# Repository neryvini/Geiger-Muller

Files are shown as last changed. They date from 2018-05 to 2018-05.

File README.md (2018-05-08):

# Geiger-Muller
Projeto desenvolvido durante a disciplina de TG para o curso de engenharia de energia da UFABC.

Resumo
--------

Detectores de radiação baseados em câmaras de gás continuam sendo utilizados para a
verificação de radioatividade, são diversos os modelos e princípios de funcionamento, cada
um com uma especificidade característica do fenômeno e caracterização a se observar. Neste
trabalho, desenvolveu um detector de radiação a gás, conhecido pelo nome de contador
Geiger-Müller.

Este desenvolvimento incluiu o aperfeiçoamento de uma fonte de alta voltagem ajustável,
compatível com os mais diversos modelos comerciais de tubos Geiger-Müller. Foi do escopo
deste projeto a implementação de um sistema microprocessado para a contagem dos
pulsos, conversão em taxa de dose de radiação, transmissão via interface e protocolo de
comunicação industrial, além de informar em tempo real para o usuário por meio de uma
tela de LCD os parâmetros de radiação detectados.

Testou-se o produto desenvolvido com os tubos SI-3BG e SBM-20, em ambos os testes os
valores detectados para a radiação de fundo foram consistentes com o esperado.

Palavras-chave: Eletrônica nuclear; Contador Geiger-Müller; Sistemas microprocessados.

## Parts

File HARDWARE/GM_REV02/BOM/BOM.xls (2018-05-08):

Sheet: BOM
Des.Ref. | Valor | Tipo
C1 | 10uF x 16V | POLCAP
C2 | 10uF x 16V | POLCAP
C3 | 100nF x 50V | CAP
C4 | 1nF x 50V | CAP
C5 | 10nF | CAP
C6 | 10n 1000V | CAP200
C7 | 10n 1000V | CAP200
C8 | 10n 1000V | CAP200
C9 | 220pF | CAP
C10 | 100uF x 50V | POLCAP
C11 | 100uF x 50V | POLCAP
C12 | 100nF x 50V | CAP_0805
C13 | 100nF x 50V | CAP_0805
C14 | 100nF x 50V | CAP
C15 | 100nF x 50V | CAP
C16 | 100nF x 50V | CAP
C17 | 100nF x 50V | CAP
C18 | 680uF x 50V | POLCAP
C19 | 220uF x 25V | POLCAP
C20 | 100n | CAP_0805
C21 | 100nF | CAP_0805
C22 | 100nF | CAP_0805
C23 | 22pF | CAP_0805
C24 | 22pF | CAP_0805
C25 | 100nF | CAP_0805
C26 | 100nF | CAP_0805
C27 | 100nF | CAP_0805
D1 | 1N4937 | DIODE
D2 | 1N4937 | DIODE
D3 | 1N4937 | DIODE
D4 | 3mm Round | LED-3R_Red
D5 | 1N5824 | DIO_SCHOTTKY
D6 | LED | DIODE_0805
D7 | LED | DIODE_0805
D8 | 1N4148 | DIODE_0805
DS1 | DISPLAY 1602 | TUXGR_16X2_R2
J1 | Jumper 5mm | OSTTA020161B
J2 | soldered | JUMPER 2
J3 | CON +24V | HDR-1x2
J4 | header | 5103308-1
J5 | CON HV | HDR-1x2
J6 | CON RS485 | HDR-1x3
L1 | 100uH - radial | IND
L2 | 10mH | 7447471
L3 | 33uH | B82477G2
L4 | 1uH | IND_0805
LS1 | Buzzer 5VDC | AST-01508MR-R
Q1 | MPSA42 | MPSA42
Q2 | 2N3904 | 2N3904
Q3 | 2N3904 | 2N3904
Q4 | 2N3904 | 2N3904
Q5 | BC817 | BC817
R1 | 33k | RES
R2 | 33k | RES
R3 | 3K | RES
R4 | 100R | 3296W
R5 | 100k | RES
R6 | 10M | RES
R7 | 10k | RES
R8 | 100k | RES
R9 | 47k | RES
R10 | 100K | RES
R11 | 470k | RES
R12 | 10k | RES
R13 | 1k | RES
R14 | 1M | RES_0805
R15 | 100K | RES_0805
R16 | 2K2 | RES_0805
R17 | 10k | RES_0805
R18 | 10k | RES_0805
R19 | 10k | RES_0805
R20 | 120R | RES_0805
R21 | 470R | RES_0805
R22 | 470R | RES_0805
R23 | 2K2 | RES_0805
R24 | 10k | RES_0805
R25 | 10k | RES_0805
R26 | 10K | 3006P
R27 | 220R | RES_0805
R28 | 10k | RES_0805
R29 | 10M | RES
R30 | 10M | RES
R31 | 10M | RES
R32 | 10M | RES
R33 | 10M | RES
R34 | VAR 25V | 711241
R35 | 10M | RES
R36 | 10M | RES
R37 | 10M | RES
R38 | 10M | RES
R39 | 10M | RES
R40 | 100K | RES
R41 | 100R 1W | RES_2512
U1 | LM555 | LM555CJ
U2 | LM555 | LM555CJ
U3 | REG. TENSAO | LM2596S-5.0
U4 | MAX485CSA | MAX485CSA
U5 | atmega328p-au | ATMEGA88_TQFP
Y1 | 16MHz | HC49S

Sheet: Plan1
Referência | Descrição | Encapsulamento | Valor
C1 | Capacitor eletrolítico - 5x12 mm | POLCAP PTH | 10uF x 16V
C2 | Capacitor eletrolítico - 5x12 mm | POLCAP PTH | 10uF x 16V
C3 | Capacitor disco cerâmico | CAP PTH | 100nF x 50V
C4 | Capacitor disco cerâmico | CAP PTH | 1nF x 50V
C5 | Capacitor disco cerâmico | CAP PTH | 10nF
C6 | Capacitor cerâmico | CAP200 PTH | 10nF x 1000V
C7 | Capacitor cerâmico | CAP200 PTH | 10nF x 1000V
C8 | Capacitor cerâmico | CAP200 PTH | 10nF x 1000V
C9 | Capacitor disco cerâmico | CAP PTH | 220pF x 50V
C10 | Capacitor eletrolítico - 5x12 mm | POLCAP PTH | 100uF x 50V
C11 | Capacitor eletrolítico - 5x12 mm | POLCAP PTH | 100uF x 50V
C12 | Capacitor cerâmico SMD - 0805 | CAP 0805 SMD | 100nF x 50V
C13 | Capacitor cerâmico SMD - 0805 | CAP 0805 SMD | 100nF x 50V
C14 | Capacitor disco cerâmico | CAP PTH | 100nF x 50V
C15 | Capacitor disco cerâmico | CAP PTH | 100nF x 50V
C16 | Capacitor disco cerâmico | CAP PTH | 100nF x 50V
C17 | Capacitor disco cerâmico | CAP PTH | 100nF x 50V
C18 | Capacitor eletrolítico - 12.5x25 mm | POLCAP PTH | 680uF x 50V
C19 | Capacitor eletrolítico - 8x12.5 mm | POLCAP PTH | 220uF x 25V
C20 | Capacitor cerâmico SMD - 0805 | CAP 0805 SMD | 100nF x 50V
C21 | Capacitor cerâmico SMD - 0805 | CAP 0805 SMD | 100nF x 50V
C22 | Capacitor cerâmico SMD - 0805 | CAP 0805 SMD | 100nF x 50V
C23 | Capacitor cerâmico SMD - 0805 | CAP 0805 SMD | 22pF x 50V
C24 | Capacitor cerâmico SMD - 0805 | CAP 0805 SMD | 22pF x 50V
C25 | Capacitor cerâmico SMD - 0805 | CAP 0805 SMD | 100nF x 50V
C26 | Capacitor cerâmico SMD - 0805 | CAP 0805 SMD | 100nF x 50V
C27 | Capacitor cerâmico SMD - 0805 | CAP 0805 SMD | 100nF x 50V
D1 | Diodo rápido PTH | DIODO | 1N4937
D2 | Diodo rápido PTH | DIODO | 1N4937
D3 | Diodo rápido PTH | DIODO | 1N4937
D4 | LED vermelho | LED 3mm | 3mm
D5 | Diodo schottky | DIO_SCHOTTKY | 1N5824
D6 | LED amarelo SMD 0805 | DIODE 0805 SMD | LED 0805
D7 | LED amarelo SMD 0805 | DIODE 0805 SMD | LED 0805
D8 | Diodo zener SMD 1206 | DIODE 1206 SMD | 1N4148
DS1 | Display 16x02 HITACHI | DISPLAY | DISPLAY 1602
J1 | Conector passo 5.08 mm | CONECTOR | 5mm
J2 | Jumper | JUMPER 2 | soldered
J3 | Jumper - passo 2.54 mm | 1x2 | CON +24V
J4 | CONECTOR HEADER | HEADER | 2x5
J5 | Jumper - passo 2.54 mm | 1x2 | CON HV
J6 | Jumper - passo 2.54 mm | 1x3 | CON RS485
L1 | Indutor PTH AXIAL | IND PTH | 100uH - radial
L2 | INDUTOR PTH 8.5x12 mm | IND PTH | 10mH
L3 | Indutor SMD - 12x12x6 mm | IND SMD | 100uH
L4 | Indutor SMD 0805 | IND SMD 0805 | 1uH
LS1 | Buzzer | BUZZER | 5 Vdc
Q1 | Transistor NPN - alta tensão | TO92 | MPSA42
Q2 | Transistor NPN - baixo sinal | TO92 | 2N3904
Q3 | Transistor NPN - baixo sinal | TO92 | 2N3904
Q4 | Transistor NPN - baixo sinal | TO92 | 2N3904
Q5 | Transistor NPN - uso geral | SOT23-3 | BC817
R1 | Resistor 1/4 W - PTH | RES PTH | 33 kΩ
R2 | Resistor 1/4 W - PTH | RES PTH | 33 kΩ
R3 | Resistor 1/4 W - PTH | RES PTH | 3 kΩ
R4 | Trimpot - 25 Voltas | 3296W | 100 Ω
R5 | Resistor 1/4 W - PTH | RES PTH | 100 kΩ
R6 | Resistor 1/4 W - PTH | RES PTH | 10 MΩ
R7 | Resistor 1/4 W - PTH | RES PTH | 10 kΩ
R8 | Resistor 1/4 W - PTH | RES PTH | 100 kΩ
R9 | Resistor 1/4 W - PTH | RES PTH | 47 kΩ
R10 | Resistor 1/4 W - PTH | RES PTH | 100 KΩ
R11 | Resistor 1/4 W - PTH | RES PTH | 470 kΩ
R12 | Resistor 1/4 W - PTH | RES PTH | 10 kΩ
R13 | Resistor 1/4 W - PTH | RES PTH | 1 kΩ
R14 | Resistor 1/8 W - SMD 0805 | RES 0805 SMD | 1 MΩ
R15 | Resistor 1/8 W - SMD 0805 | RES 0805 SMD | 100 KΩ
R16 | Resistor 1/8 W - SMD 0805 | RES 0805 SMD | 2.2 kΩ
R17 | Resistor 1/8 W - SMD 0805 | RES 0805 SMD | 10 kΩ
R18 | Resistor 1/8 W - SMD 0805 | RES 0805 SMD | 10 kΩ
R19 | Resistor 1/8 W - SMD 0805 | RES 0805 SMD | 10 kΩ
R20 | Resistor 1/8 W - SMD 0805 | RES 0805 SMD | 120 Ω
R21 | Resistor 1/8 W - SMD 0805 | RES 0805 SMD | 470 Ω
R22 | Resistor 1/8 W - SMD 0805 | RES 0805 SMD | 470 Ω
R23 | Resistor 1/8 W - SMD 0805 | RES 0805 SMD | 2.2 kΩ
R24 | Resistor 1/8 W - SMD 0805 | RES 0805 SMD | 10 kΩ
R25 | Resistor 1/8 W - SMD 0805 | RES 0805 SMD | 10 kΩ
R26 | Trimpot - 10 Voltas | 3006P | 10 kΩ
R27 | Resistor 1/8 W - SMD 0805 | RES 0805 SMD | 220 Ω
R28 | Resistor 1/8 W - SMD 0805 | RES 0805 SMD | 10 kΩ
R29 | Resistor 1/4 W - PTH | RES PTH | 10 MΩ
R30 | Resistor 1/4 W - PTH | RES PTH | 10 MΩ
R31 | Resistor 1/4 W - PTH | RES PTH | 10 MΩ
R32 | Resistor 1/4 W - PTH | RES PTH | 10 MΩ
R33 | Resistor 1/4 W - PTH | RES PTH | 10 MΩ
R34 | Varistor 10K25 | VARISTOR | VAR 25V
R35 | Resistor 1/4 W - PTH | RES PTH | 10 MΩ
R36 | Resistor 1/4 W - PTH | RES PTH | 10 MΩ
R37 | Resistor 1/4 W - PTH | RES PTH | 10 MΩ
R38 | Resistor 1/4 W - PTH | RES PTH | 10 MΩ
R39 | Resistor 1/4 W - PTH | RES PTH | 10 MΩ
R40 | Resistor 1/4 W - PTH | RES PTH | 100 KΩ
R41 | Resistor 1 W - SMD 2512 | RES 2512 SMD | 100Ω 1W
U1 | Circuito integrado LM555 CMOS | DIP-8 | LM555
U2 | Circuito integrado LM555 CMOS | DIP-8 | LM555
U3 | Regulador de tensão chaveado | TO-263 | REG. TENSAO
U4 | Circuito integrado MAX485CSA | SOIC8 | MAX485CSA
U5 | Circuito integrado m328P | TQFP | ATMEGA328P-AU
Y1 | Cristal HC-49S | HC-49S | 16 MHz

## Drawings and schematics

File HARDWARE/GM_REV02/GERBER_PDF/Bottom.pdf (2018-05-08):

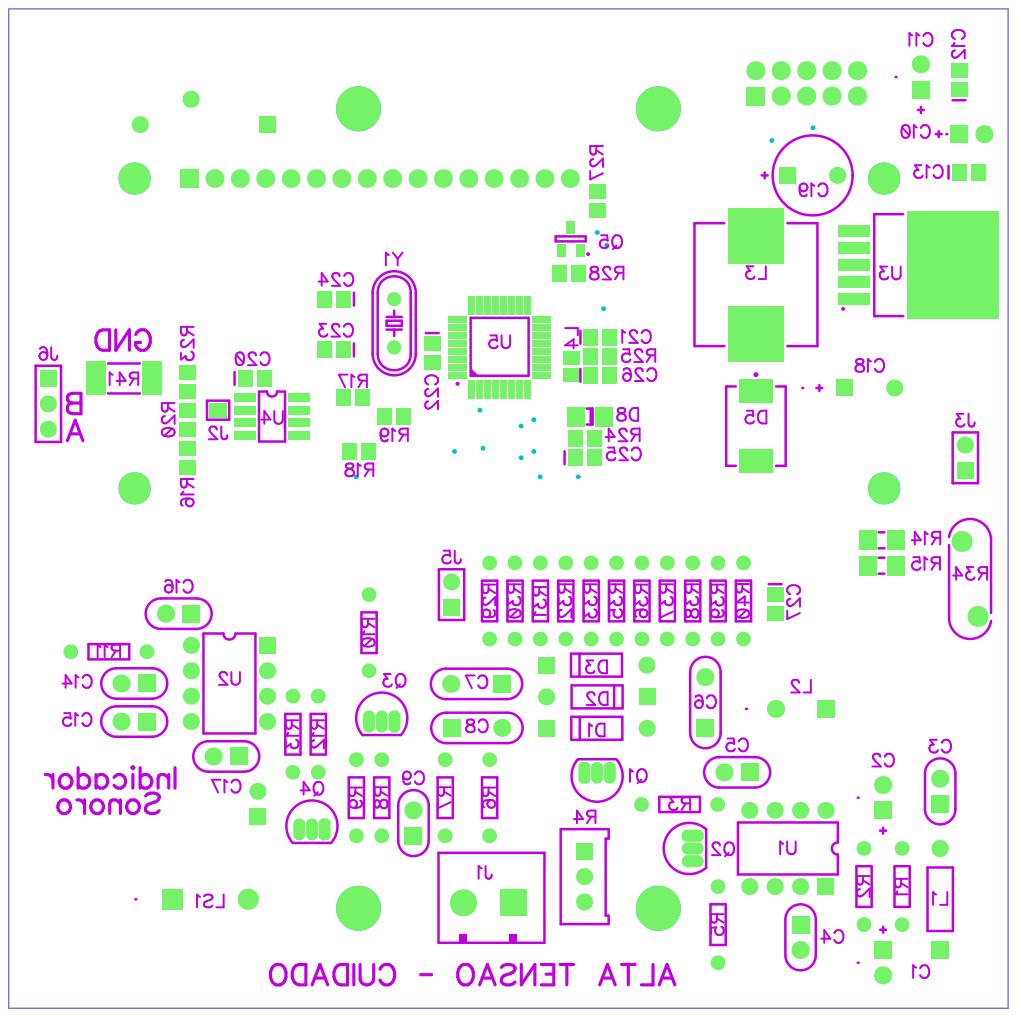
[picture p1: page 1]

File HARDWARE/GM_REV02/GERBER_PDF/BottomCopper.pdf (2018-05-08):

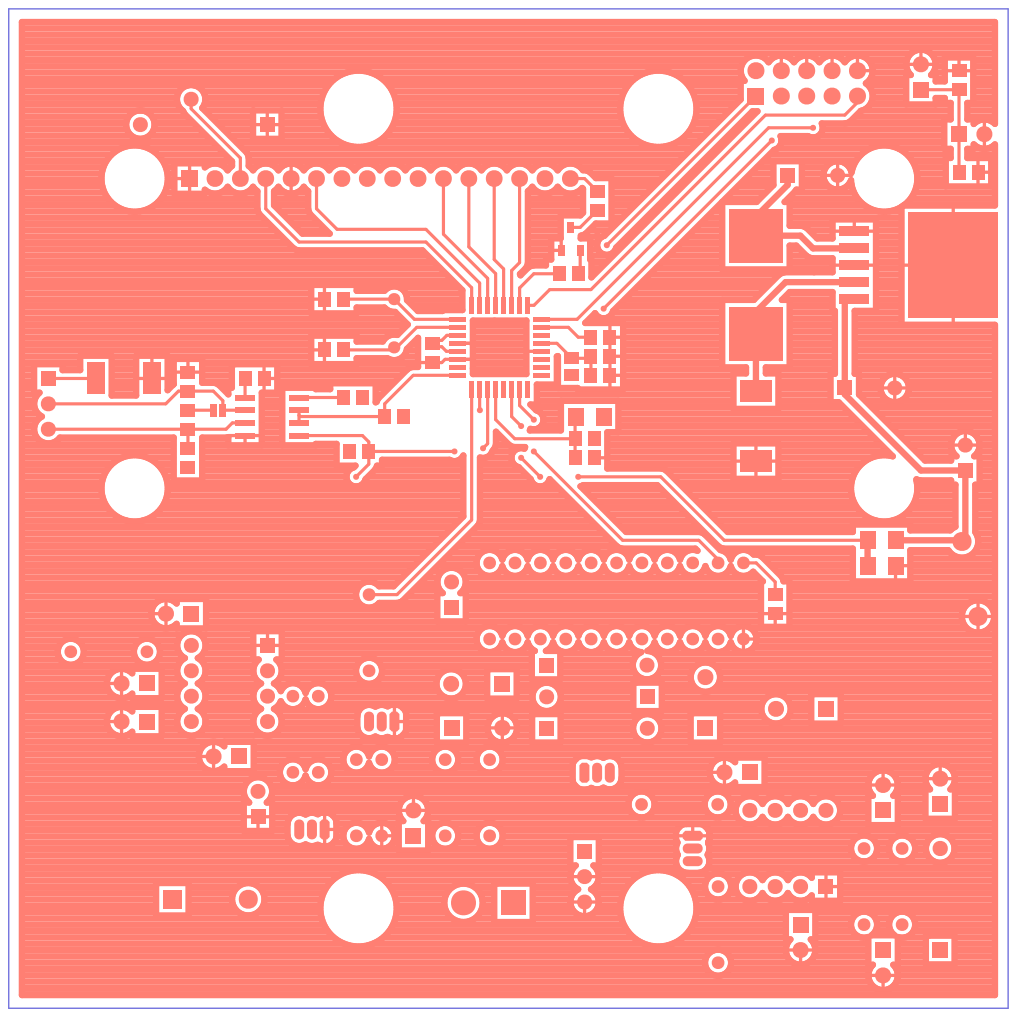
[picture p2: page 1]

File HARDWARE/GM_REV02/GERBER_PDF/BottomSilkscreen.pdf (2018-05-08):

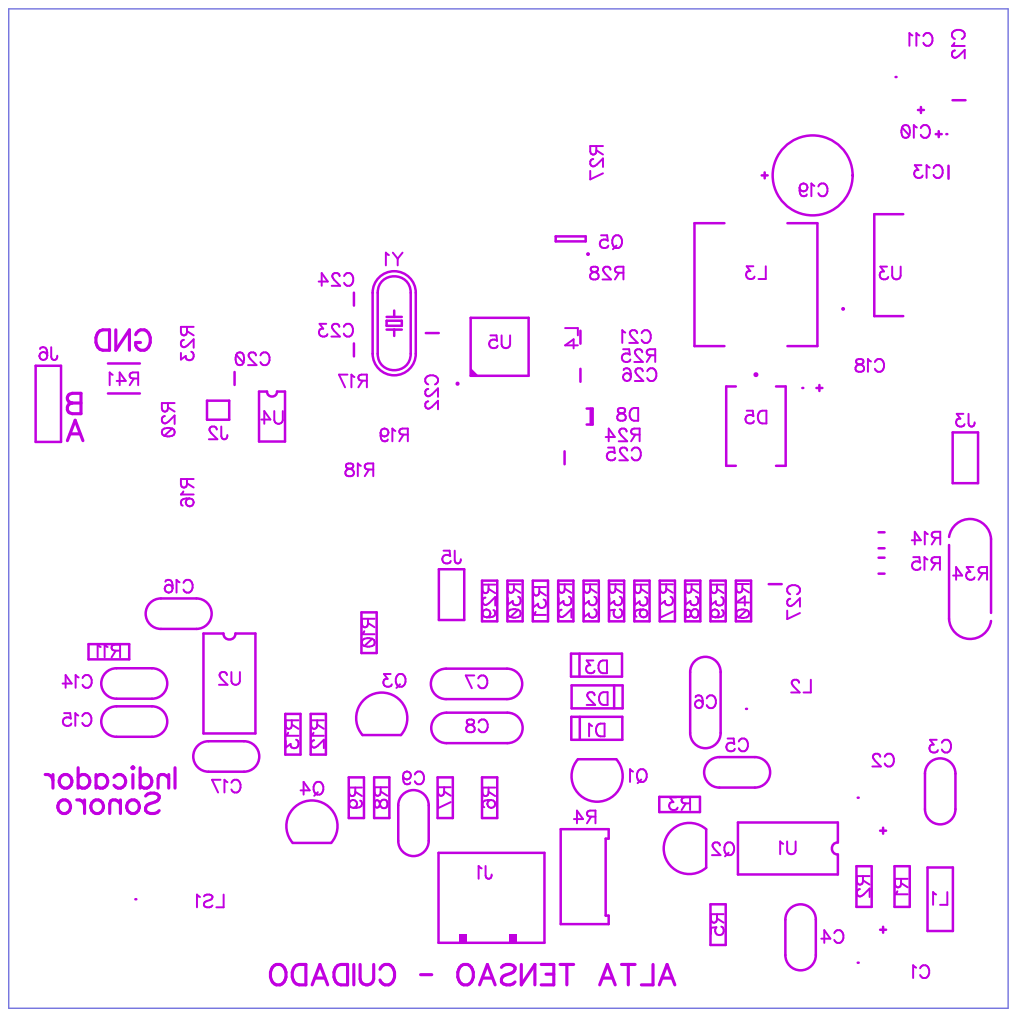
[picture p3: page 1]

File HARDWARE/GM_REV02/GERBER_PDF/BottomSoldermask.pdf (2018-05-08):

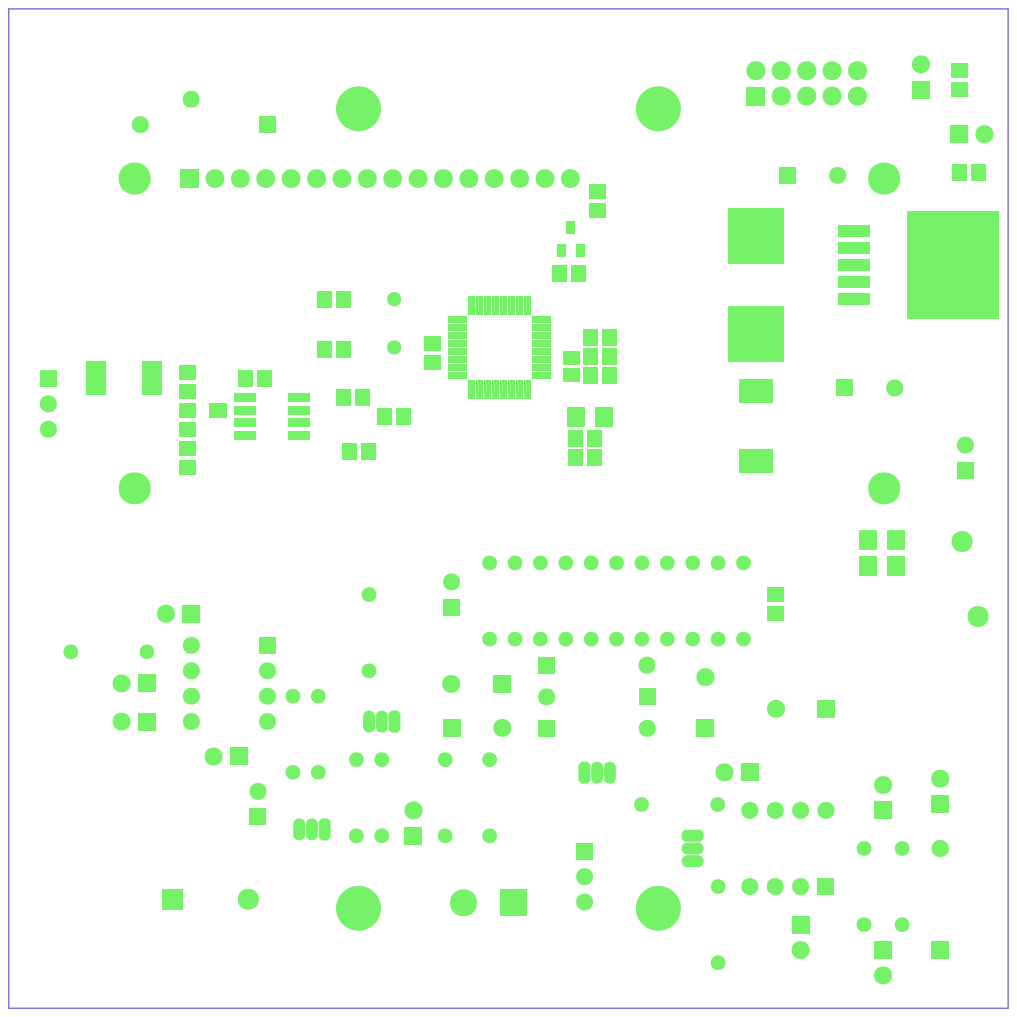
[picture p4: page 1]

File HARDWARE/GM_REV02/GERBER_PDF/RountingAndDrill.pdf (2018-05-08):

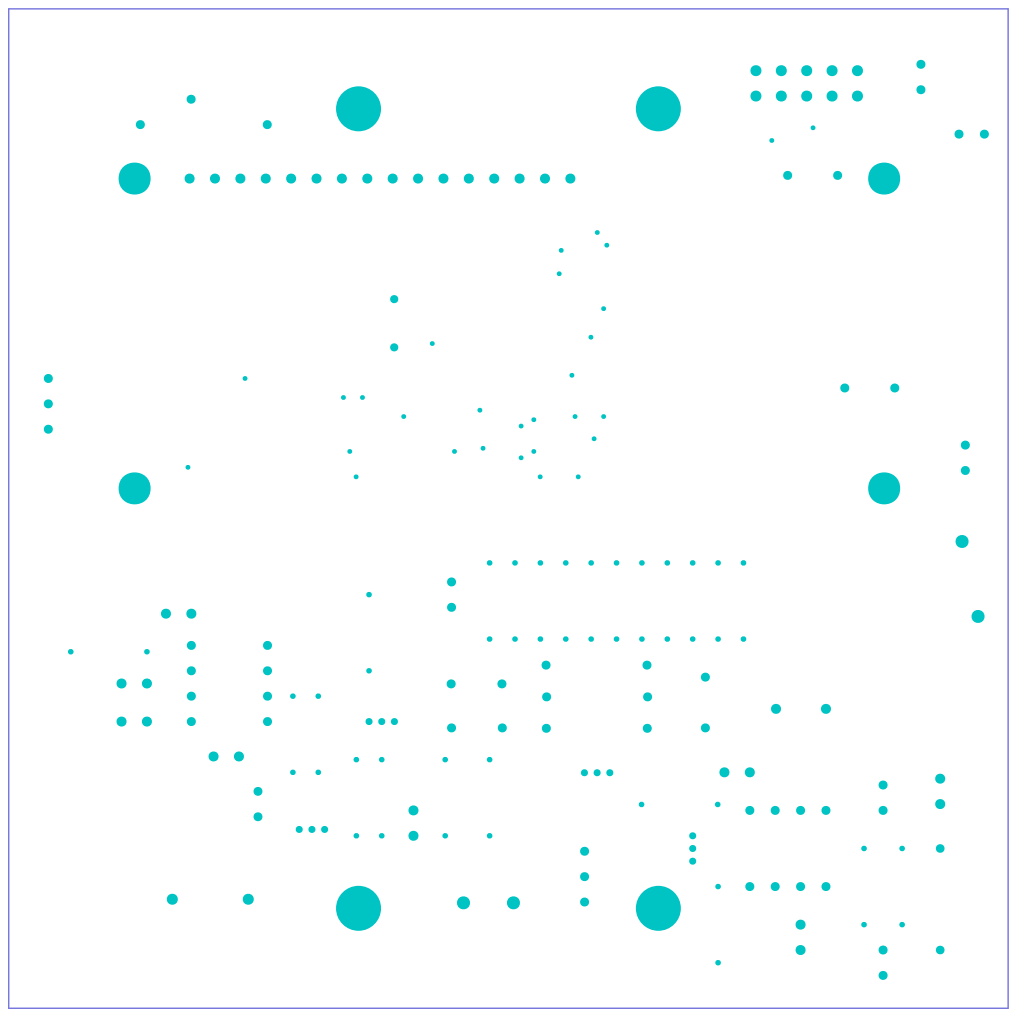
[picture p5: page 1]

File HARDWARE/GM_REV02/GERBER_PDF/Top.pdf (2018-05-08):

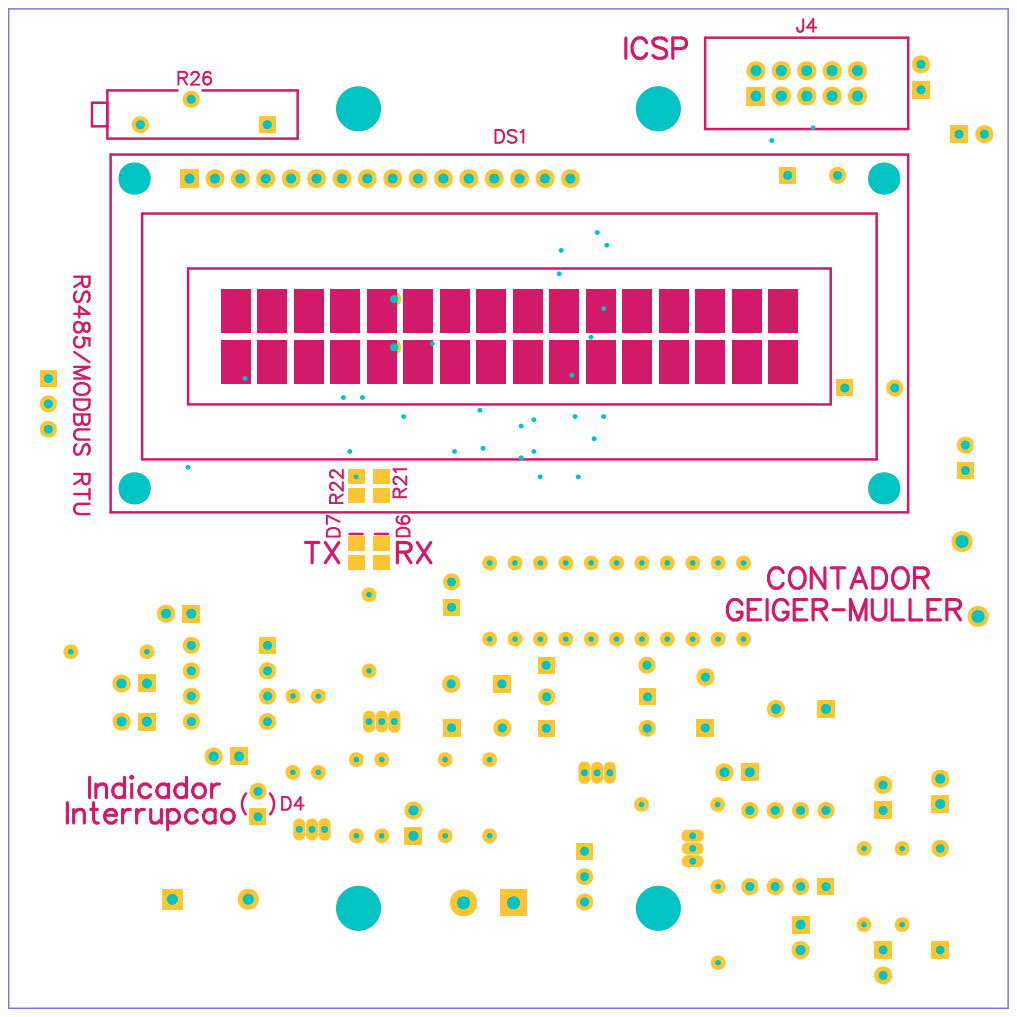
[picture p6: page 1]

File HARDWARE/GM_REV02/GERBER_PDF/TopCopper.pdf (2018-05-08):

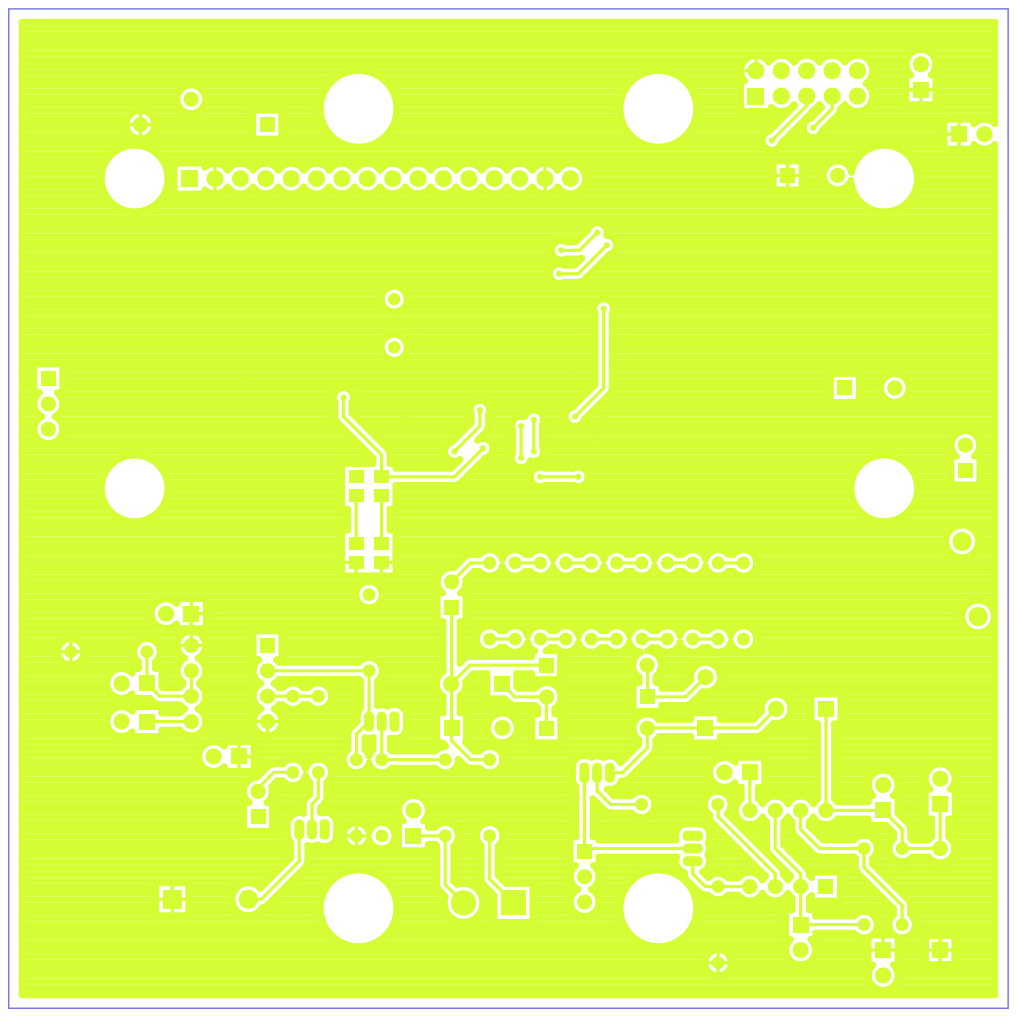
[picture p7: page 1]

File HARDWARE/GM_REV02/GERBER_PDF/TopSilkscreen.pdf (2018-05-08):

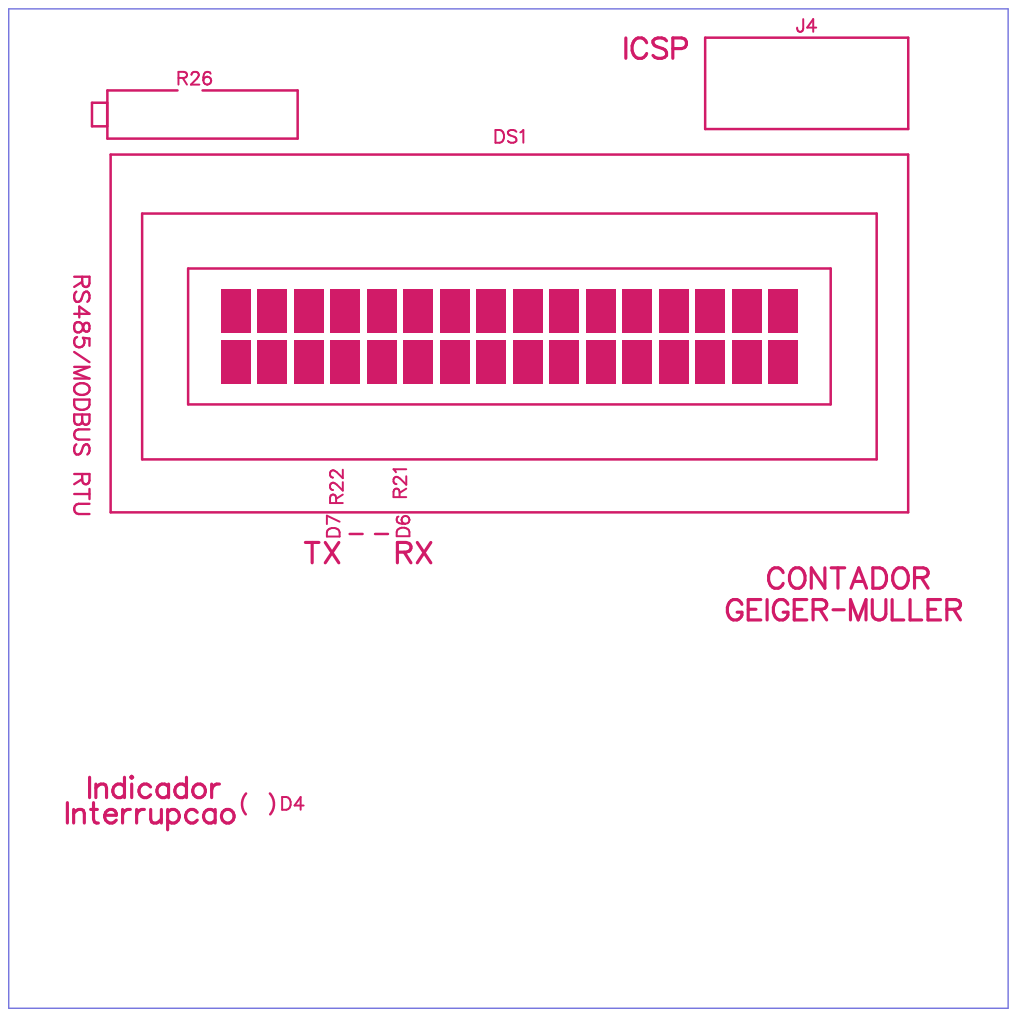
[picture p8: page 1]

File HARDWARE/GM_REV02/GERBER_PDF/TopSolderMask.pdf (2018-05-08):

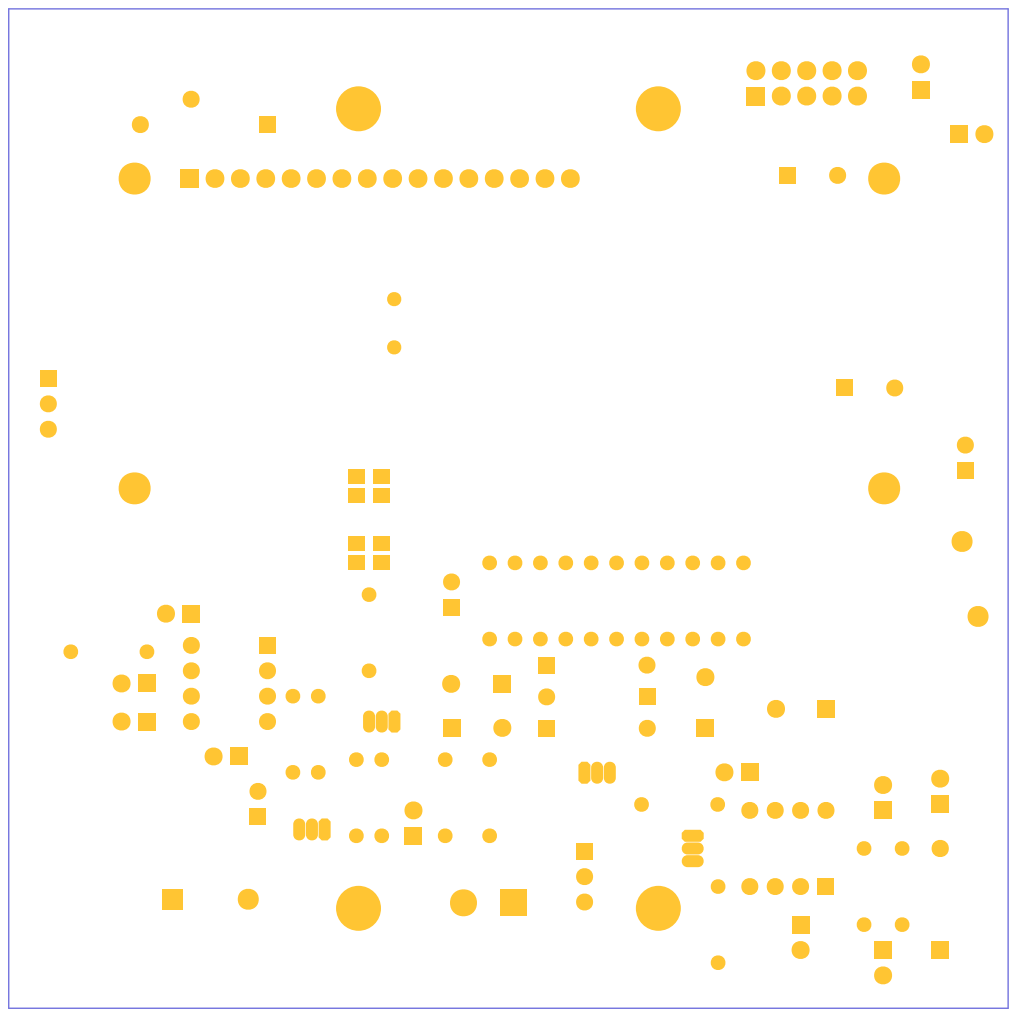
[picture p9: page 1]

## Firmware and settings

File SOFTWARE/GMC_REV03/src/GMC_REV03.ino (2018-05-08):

#include <EEPROMex.h>
#include <Arduino.h>
#include <EEPROMVar.h>
#include <elapsedMillis.h>
#include <avr/wdt.h>
#include <LiquidCrystal.h>
#include <SimpleModbusSlave.h>

//************ Define o pino em que a leitura de tensao e feito
#define HVTP A3
#define DBL 11

//************ Define o ponto de teste de alta tensao
float HVTPOINT;

//************ Define as conexoes do LCD
LiquidCrystal lcd(5, 6, 7, 8, 9, 10);

//************ Cria o caracter Micro
byte micro[8] = {
	0b00000,
	0b10001,
	0b10001,
	0b10011,
	0b11101,
	0b10000,
	0b10000,
	0b10000
};

//************ Variaveis responsaveis pelo tempo de execucao
elapsedMillis pMillis;
int tempo     = 0;
unsigned int interval  = 1000;

//************ Variaveis responsaveis pela media movel das contagens
unsigned int CPMLM  = 0;
unsigned long oCPMLM  = 0;

//************ Fator de conversao especifico para o tubo SBM-20m
const float convFact = 0.5747126; //--------------> Tube datasheet
//************ Variavel para armazenar o valor em microroentgen por hora
float microroentgen_hour = 0.0;

//----------------------Simple Moving Average------------------------
//************ Vetor com sessenta posicoes para armazenar as sessenta contagens de um minuto
int SA[60];
int aSA     = 0;
int sample  = 0;
long AVGA    = 0;

//************ Biblioteca modbus de terceiro

// ------------------- MODBUS --------------
/* This example code has 9 holding registers. 6 analogue inputs, 1 button, 1 digital output
   and 1 register to indicate errors encountered since started.
   Function 5 (write single coil) is not implemented so I'm using a whole register
   and function 16 to set the onboard Led on the Atmega328P.

   The modbus_update() method updates the holdingRegs register array and checks communication.

   Note:
   The Arduino serial ring buffer is 128 bytes or 64 registers.
   Most of the time you will connect the arduino to a master via serial
   using a MAX485 or similar.

   In a function 3 request the master will attempt to read from your
   slave and since 5 bytes is already used for ID, FUNCTION, NO OF BYTES
   and two BYTES CRC the master can only request 122 bytes or 61 registers.

   In a function 16 request the master will attempt to write to your
   slave and since a 9 bytes is already used for ID, FUNCTION, ADDRESS,
   NO OF REGISTERS, NO OF BYTES and two BYTES CRC the master can only write
   118 bytes or 59 registers.

   Using the FTDI USB to Serial converter the maximum bytes you can send is limited
   to its internal buffer which is 60 bytes or 30 unsigned int registers.

   Thus:

   In a function 3 request the master will attempt to read from your
   slave and since 5 bytes is already used for ID, FUNCTION, NO OF BYTES
   and two BYTES CRC the master can only request 54 bytes or 27 registers.

   In a function 16 request the master will attempt to write to your
   slave and since a 9 bytes is already used for ID, FUNCTION, ADDRESS,
   NO OF REGISTERS, NO OF BYTES and two BYTES CRC the master can only write
   50 bytes or 25 registers.

   Since it is assumed that you will mostly use the Arduino to connect to a
   master without using a USB to Serial converter the internal buffer is set
   the same as the Arduino Serial ring buffer which is 128 bytes.
*/


// Using the enum instruction allows for an easy method for adding and
// removing registers. Doing it this way saves you #defining the size
// of your slaves register array each time you want to add more registers
// and at a glimpse informs you of your slaves register layout.

//////////////// registers of your slave ///////////////////
enum
{
  // just add or remove registers and your good to go...
  // The first register starts at address 0
  ADDR0,
  ADDR1,

  TOTAL_ERRORS,
  // leave this one
  TOTAL_REGS_SIZE
  // total number of registers for function 3 and 16 share the same register array
};

unsigned int holdingRegs[TOTAL_REGS_SIZE]; // function 3 and 16 register array


void setup()
{
	//--------------- MODBUS Slave ---------------
	/* parameters(long baudrate,
								unsigned char ID,
								unsigned char transmit enable pin,
								unsigned int holding registers size,
								unsigned char low latency)

		 The transmit enable pin is used in half duplex communication to activate a MAX485 or similar
		 to deactivate this mode use any value < 2 because 0 & 1 is reserved for Rx & Tx.
		 Low latency delays makes the implementation non-standard
		 but practically it works with all major modbus master implementations.
	*/

modbus_configure(9600, 10, 3, TOTAL_REGS_SIZE, 0);

pinMode(DBL, OUTPUT);
digitalWrite(DBL, HIGH);

//************ Habilita as interrupcoes
attachInterrupt(0, incpulso, RISING);

//************ Cria o caracter micro
lcd.createChar(0, micro);

//************ Inicia o lcd
lcd.begin(16, 2);

//************ Define a posicao do cursor e escreve as informacoes de boas vindas
lcd.setCursor(4, 0);
lcd.print("CONTADOR");
lcd.setCursor(1, 1);
lcd.print("GEIGER-MULLER");
delay(3000);

lcd.clear();

lcd.setCursor(0, 0);
lcd.print("Hardware: VER04");
lcd.setCursor(0, 1);
lcd.print("Software: VER03");
delay(2000);

lcd.clear();
//************ Zera o timer
pMillis = 0;

}

void loop()
{
	//************ Chama a funcao CPM em cada volta do codigo
	CPM();
	//************ Le a tensao no pino de alta tensao
	analogRead(HVTP);

	//************ Converte a tensao com base no divisor de tensao de 100M
	HVTPOINT = analogRead(HVTP) * 5221.271885 / 1024.0;
	//************ Verifica se o jumper de alta tensao esta em uso, isto e feito analisando o valor do sinal
	//************ caso nao esteja em uso e feita a escrita dos valores de CPM na tela
	if(HVTPOINT < 100.0)
	{
		lcd.setCursor(0, 0);
		lcd.print("CPM:");
		lcd.setCursor(6, 0);
		lcd.print(oCPMLM);

		lcd.setCursor(0, 1);
		lcd.write(byte(0));
		lcd.setCursor(1, 1);
		lcd.print("R/h:");
		lcd.setCursor(6, 1);
		lcd.print(microroentgen_hour, 2);
	}
	//************ Caso o jumper esteja posicionado para ajuste da fonte, o valor da tensao e impresso na tela
	else {
		lcd.setCursor(0, 0);
		lcd.print(" TENSAO GERADOR");
		lcd.setCursor(13, 1);
		lcd.print("[V]");
		lcd.setCursor(4, 1);
		lcd.print(HVTPOINT, 1);
	}
}

void CPM() //----Funcao responsavel por realizar a conta de pulsos por minuto
{
  if (interval - pMillis <= 50)
  {
    tempo       = interval - pMillis;
    delay(tempo);
    cli();           //----------------  Desabilita a interrupcao
    oCPMLM = SMACPM(CPMLM);  //---------------- old Count Per Minute Last Minute equals CPMLM
    CPMLM = 0;       //---------------- Restart the counter
    pMillis = 0;     //----------------  Zera o timer da interrupcao
    sei();           //----------------  Habilita a interrupcao
		microroentgen_hour = convFact * oCPMLM; //-------------------- Convert CPM to mR/h
		lcd.clear();
		mbus();
    }
}

void incpulso () //------- Incrementa os pulso -------
{
  CPMLM++;
}

//************Media movel das interrupcoes em um minuto
long SMACPM(long CPS)
{
  AVGA    = 0;
  sample  = 0;
  SA[aSA] = CPS;
  for (sample = 0; sample <= 58; sample++)
  {
    AVGA += SA[sample];
  }
  if (aSA <= 58)
  {
    aSA++;
  } else
  {
    aSA = 0;
  }
  return AVGA;
}

//************ Funcao responsavel pelos dados enviados pelo protocolo modbus
void mbus()
{
  holdingRegs[TOTAL_ERRORS] = modbus_update(holdingRegs);

  holdingRegs[ADDR0] = oCPMLM;
  holdingRegs[ADDR1] = HVTPOINT;
}
